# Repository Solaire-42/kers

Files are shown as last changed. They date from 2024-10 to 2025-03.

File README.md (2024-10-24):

# kers
Kinetic Energy Recovery System

⠀⠀⠀⠀⠀⠀⠀⠀⠀⠀⠀⠀⠀⠀⠀⠀⠀⠀⠀⠀⠀⠀⠀⠀⠀⠀⠀⠀⠀⠀⠀⠀⠀⠀⠀⠀⠀⠀⠀⠀⠀⠀⠀⣠⠀⠀⠀⠀⠀⠀⠀⠀⠀⠀⠀⠀⠀
⠀⠀⠀⠀⠀⠀⠀⠀⠀⠀⠀⠀⠀⠀⠀⠀⠀⠀⠀⠀⠀⠀⠀⠀⠀⠀⠀⠀⠀⠀⠀⠀⠀⠀⠀⠀⠀⠀⠀⠸⣿⣿⣿⣿⠀⠀⠀⠀⠀⠀⠀⠀⠀⠀⠀⠀⠀
⠀⠀⠀⠀⠀⠀⠀⠀⠀⠀⠀⠀⠀⠀⠀⠀⠀⠀⠀⠀⠀⠀⠀⠀⠀⠀⠀⠀⠀⠀⠀⠀⠀⠀⠀⠀⠀⠀⢠⣿⣿⣿⠛⠁⠀⠀⠀⠀⠀⠀⠀⠀⠀⠀⠀⠀⠀
⠀⠀⠀⠀⠀⠀⠀⠀⠀⠀⠀⠀⠀⠀⠀⠀⠀⠀⠀⠀⠀⠀⠀⠀⠀⠀⠀⠀⠀⠀⠀⠀⠀⠀⠀⣶⣶⣶⣿⢿⣿⣥⡄⠀⠀⠀⠀⠀⠀⠀⠀⠀⠀⠀⠀⠀⠀
⠀⠀⠀⠀⠀⠀⠀⠀⠀⠀⠀⠀⠀⠀⠀⠀⠀⠀⠀⠀⠀⠀⠀⠀⠀⠀⠀⠀⠀⠀⠀⠀⢀⣤⣾⡿⠟⠉⠀⠸⣿⡄⠀⠀⠀⠀⠀⠀⠀⠀⠀⠀⠀⠀⠀⠀⠀
⠀⠀⠀⠀⠀⠀⠀⠀⠀⠀⠀⠀⠀⠀⠀⠀⠀⠀⠀⠀⠀⠀⠀⠀⠀⠀⠀⠀⠀⢀⣠⣶⠟⠋⠁⠀⠀⠀⠀⠀⣿⣇⠀⠀⠀⠀⠀⠀⠀⠀⠀⠀⠀⠀⠀⠀⠀
⠀⠀⠀⠀⠀⠀⠀⠀⠀⠀⠀⠀⠀⠀⠀⠀⠀⠀⠀⠀⠀⠀⠀⠀⠀⠀⠀⣀⣴⡾⠋⠁⠀⠀⠀⠀⠀⠀⠀⠀⠘⣿⠀⠀⠀⠀⠀⠀⠀⠀⠀⠀⠀⠀⠀⠀⠀
⠀⠀⠀⠀⠀⠀⠀⠀⠀⠀⠀⠀⠀⠀⠀⠀⠀⠀⠀⠀⠀⠀⠀⠀⠀⣠⣾⠟⠁⠀⠀⠀⠀⠀⠀⠀⠀⠀⠀⠀⠀⣿⡇⠀⠀⠀⠀⠀⠀⠀⠀⠀⠀⠀⠀⠀⠀
⠀⠀⠀⠀⠀⠀⠀⠀⠀⠀⠀⠀⠀⠀⠀⠀⠀⠀⠀⠀⠀⠀⠀⢠⣾⠟⠁⠀⠀⠀⠀⠀⠀⠀⠀⠀⠀⠀⠀⠀⠀⠸⣧⠀⠀⠀⠀⠀⠀⠀⠀⠀⠀⠀⠀⠀⠀
⠀⠀⠀⠀⠀⠀⠀⠀⠀⠀⠀⠀⠀⠀⠀⠀⠀⠀⠀⠀⠀⠀⣰⡿⠃⠀⠀⠀⠀⠀⠀⠀⠀⠀⠀⠀⠀⠀⠀⠀⠀⠀⣿⡄⠀⠀⠀⠀⠀⠀⠀⠀⠀⠀⠀⠀⠀
⠀⠀⠀⠀⠀⠀⠀⠀⠀⠀⠀⠀⠀⠀⠀⠀⠀⠀⠀⠀⠀⣼⡟⠀⠀⠀⠀⠀⠀⠀⠀⠀⠀⠀⠀⠀⠀⠀⠀⠀⠀⠀⢸⡇⠀⠀⠀⠀⠀⠀⠀⠀⠀⠀⠀⠀⠀
⠀⠀⠀⠀⠀⠀⠀⠀⠀⠀⠀⠀⠀⠀⠀⠀⠀⠀⠀⠀⣾⡏⠀⠀⠀⠀⠀⠀⠀⠀⠀⠀⠀⠀⠀⠀⠀⠀⠀⠀⠀⠀⢸⣷⠀⠀⠀⠀⠀⠀⠀⠀⠀⠀⠀⠀⠀
⠀⠀⠀⠀⠀⠀⠀⠀⠀⠀⠀⠀⠀⠀⠀⠀⠀⠀⠀⣸⡟⠀⠀⠀⠀⠀⠀⠀⠀⠀⠀⠀⠀⠀⠀⠀⠀⠀⠀⠀⠀⠀⠸⣿⠀⠀⠀⠀⠀⠀⠀⠀⠀⠀⠀⠀⠀
⠀⠀⠀⠀⠀⠀⠀⠀⠀⠀⠀⠀⠀⠀⠀⠀⠀⠀⢰⡿⠁⠀⠀⠀⠀⠀⠀⠀⠀⠀⠀⠀⠀⠀⠀⠀⠀⠀⠀⠀⠀⠀⠀⣿⠀⠀⠀⠀⠀⠀⠀⠀⠀⠀⠀⠀⠀
⠀⠀⠀⠀⠀⠀⠀⠀⠀⠀⠀⠀⠀⠀⠀⠀⠀⠀⣿⡇⠀⠀⠀⠀⠀⠀⠀⠀⠀⠀⠀⠀⠀⠀⠀⠀⠀⠀⠀⠀⠀⠀⠀⣿⠀⠀⠀⠀⠀⠀⠀⠀⠀⠀⠀⠀⠀
⠀⠀⠀⠀⠀⠀⠀⠀⠀⠀⠀⠀⠀⠀⠀⠀⠀⢸⡟⠀⠀⠀⠀⠀⠀⠀⠀⠀⠀⠀⠀⠀⠀⠀⠀⠀⠀⠀⠀⠀⠀⠀⠀⢻⡄⠀⠀⠀⠀⠀⠀⠀⠀⠀⠀⠀⠀
⠀⠀⠀⠀⠀⠀⠀⠀⠀⠀⠀⠀⠀⠀⠀⠀⢠⣿⠁⠀⠀⠀⠀⠀⠀⠀⠀⠀⠀⠀⠀⠀⠀⠀⠀⠀⠀⠀⠀⠀⠀⠀⠀⢸⡇⠀⠀⠀⠀⠀⠀⠀⠀⠀⠀⠀⠀
⠀⠀⠀⠀⠀⠀⠀⠀⣀⣤⣠⣠⣀⣀⣀⣀⣸⣟⡀⠀⠀⠀⠀⠀⠀⠀⠀⠀⠀⠀⠀⠀⠀⠀⠀⠀⠀⠀⠀⠀⠀⠀⠀⢸⡇⠀⠀⠀⠀⠀⠀⠀⠀⠀⠀⠀⠀
⠀⠀⠀⠀⠀⣠⡶⣿⣿⣭⣿⣿⣿⣿⣿⣿⣿⣿⣿⣷⣶⡦⣤⡀⠀⠀⠀⠀⠀⠀⠀⠀⠀⠀⠀⠀⠀⠀⠀⠀⠀⠀⠀⢸⡇⠀⠀⠀⠀⠀⠀⠀⠀⠀⠀⠀⠀
⠀⠀⠀⣠⣾⢿⣿⣿⣿⣿⣿⣿⣿⣿⣿⣿⣿⣿⣿⣿⣿⣿⣮⡙⢷⣄⠀⠀⠀⠀⠀⠀⠀⠀⠀⠀⠀⠀⠀⠀⠀⠀⠀⢸⡇⠀⠀⠀⠀⠀⠀⠀⠀⠀⠀⠀⠀
⠀⢀⣼⢛⣵⣿⣿⣿⣿⣿⣿⣿⣿⣿⣿⣿⣿⣿⣿⣿⣿⣿⣿⣷⡄⠻⣧⡀⠀⠀⠀⠀⠀⠀⠀⠀⠀⠀⠀⠀⠀⠀⠀⢸⡇⠀⠀⠀⠀⠀⠀⠀⠀⠀⠀⠀⠀
⠀⣼⠃⣾⣿⣿⣿⣿⣿⣿⣿⣿⣿⣿⣿⣿⣿⣿⣿⣿⣿⣿⣿⣿⣿⡖⢻⣇⠀⠀⠀⠀⠀⠀⠀⠀⠀⠀⠀⠀⠀⠀⠀⢸⡇⠀⠀⠀⠀⠀⠀⠀⠀⠀⠀⠀⠀
⣸⡿⣴⣿⣿⣿⠟⠛⣿⣿⣿⡿⣿⣿⣿⣿⣿⣿⣿⣿⣿⣿⣿⣿⣿⣿⣾⣿⠀⠀⠀⠀⠀⠀⠀⠀⠀⠀⠀⠀⠀⠀⠀⢸⣧⠀⠀⠀⠀⠀⠀⠀⠀⠀⠀⠀⠀
⣿⡇⣿⣿⣿⡆⠰⠘⠿⠟⠉⠀⠈⢿⣿⣿⣿⣿⣿⣿⣿⣿⣿⣿⣿⣿⣿⣿⠀⠀⠀⠀⠀⠀⠀⢀⣤⣀⣀⠀⠀⠀⠀⢸⣿⠀⠀⠀⠀⠀⠀⠀⠀⠀⠀⠀⠀
⣿⠁⠏⣿⡿⡇⢀⢸⡔⠲⣄⢀⠀⢈⣿⣿⣿⣿⣿⣿⣿⣿⣿⣿⣿⣿⣿⣿⠀⠀⠀⢀⣠⣶⠿⠿⣿⣻⣿⣿⣿⣿⣶⣿⣿⣧⣤⣀⣀⡀⠀⠀⠀⠀⠀⠀⠀
⡟⠀⣄⡟⠇⠁⣼⠈⢻⣦⣙⢳⣆⢈⣿⣿⣿⣿⣿⣿⣿⣿⣿⣿⣿⣿⣿⡟⠀⢠⣴⣿⣿⣷⣾⣿⣿⣿⣿⣿⣿⣿⣿⣿⣿⣿⣿⣿⣿⣿⣷⡶⣤⡀⠀⠀⠀
⣷⡀⣿⣇⠀⠀⠹⣆⠀⠈⠙⢻⠿⣿⣿⣿⣿⣿⣿⣿⣿⣿⣿⣿⣿⣿⡿⠃⣠⣿⣿⣿⣿⣿⣿⣿⣿⣿⣿⣿⣿⣿⣿⣿⣿⣿⣿⣿⣿⣿⣿⣿⣎⠹⣦⠀⠀
⢻⣇⠈⣿⡄⠀⠀⠉⣷⠀⠀⡞⠀⢸⣿⣿⣿⣿⣿⣿⣿⣷⣿⣿⣿⣿⠁⢰⣿⣿⣿⣿⣿⣿⣿⣿⣿⣿⣿⣿⣿⣿⣿⣿⣿⣿⣿⣿⣿⣿⣿⣿⣿⣧⢻⣧⠀
⠘⢿⣆⡘⣿⠷⢤⣤⠼⠿⢴⣯⣠⣾⣿⣿⣿⣿⣿⣿⣿⣿⣿⣿⣿⠇⢠⣿⣿⣿⣿⣿⣿⣿⣿⠟⠿⣿⣿⣿⣿⣿⣿⣿⣿⣿⣿⣿⣿⣿⣿⣿⣿⣿⣿⢿⡇
⠀⠈⣯⣷⡈⣢⣠⣀⣀⡀⣀⣨⣽⣿⣿⣿⣿⣿⣿⣿⣿⣿⣿⣿⠋⠀⢸⣿⣿⢃⣿⣿⣿⣽⣿⣦⣝⠛⠛⡉⠉⢉⣻⣿⣿⣿⣿⣿⣿⣿⣿⣿⣿⣿⣿⣾⣷
⠀⠀⠈⢿⣷⠉⠉⢛⡋⠁⠛⠛⠿⣿⣿⣿⠿⠿⢿⣿⣿⣿⡿⠉⠀⠀⢸⣿⣿⣿⣿⣿⠏⣌⡀⠲⠋⠳⣄⠀⣼⣿⣿⣿⣿⣿⣿⣿⣿⣿⣿⣿⣿⣿⣿⣿⣿
⠀⠀⠀⠀⠙⢷⣄⠈⠙⠠⠄⠱⡘⢛⣶⠾⠿⠿⣿⡿⠟⠋⠀⠀⠀⠀⢸⡿⠛⣿⣿⣿⡘⢿⡃⠈⠻⣇⡀⢦⢀⣿⣿⣿⣿⣿⣿⣿⣿⣿⣿⣿⣿⣿⣿⣿⡿
⠀⠀⠀⠀⠀⠀⠉⠓⠦⠤⣄⣀⣀⣭⡥⠤⠶⠛⠋⠀⠀⠀⠀⠀⠀⠀⠸⣇⠀⠙⠿⣿⣿⣾⣯⣤⣀⣬⣥⣾⡿⠟⣰⣿⣿⣿⣿⣿⣿⣿⣿⣿⣿⣿⣿⣿⠇
⠀⠀⠀⠀⠀⠀⠀⠀⠀⠀⠈⠉⠁⠀⠀⠀⠀⠀⠀⠀⠀⠀⠀⠀⠀⠀⠀⢹⡠⠀⠀⢼⣿⣿⢻⣟⡛⣛⠉⡉⠀⣰⣿⣿⣿⣿⣿⣿⣿⣿⣿⣿⣿⣿⣿⡏⠀
⠀⠀⠀⠀⠀⠀⠀⠀⠀⠀⠀⠀⠀⠀⠀⠀⠀⠀⠀⠀⠀⠀⠀⠀⠀⠀⠀⠈⣷⡆⠀⠀⠿⣿⡇⠉⢻⣿⣿⣥⣴⣿⣿⣿⣿⣿⣿⣿⣿⣿⣿⣿⠿⢿⡟⠀⠀
⠀⠀⠀⠀⠀⠀⠀⠀⠀⠀⠀⠀⠀⠀⠀⠀⠀⠀⠀⠀⠀⠀⠀⠀⠀⠀⠀⠀⠸⣷⠀⠀⠺⣿⡃⣸⣶⣿⣿⣿⣿⣿⣿⣿⣿⣿⣿⣿⣿⣿⣿⡟⢸⠟⠀⠀⠀
⠀⠀⠀⠀⠀⠀⠀⠀⠀⠀⠀⠀⠀⠀⠀⠀⠀⠀⠀⠀⠀⠀⠀⠀⠀⠀⠀⠀⠀⠹⣧⠀⠘⠛⢦⣍⣉⠍⠻⣿⣿⣿⣿⣿⣿⣿⣿⣿⣿⣿⣏⡴⠋⠀⠀⠀⠀
⠀⠀⠀⠀⠀⠀⠀⠀⠀⠀⠀⠀⠀⠀⠀⠀⠀⠀⠀⠀⠀⠀⠀⠀⠀⠀⠀⠀⠀⠀⠘⢧⡀⠀⠀⠈⡉⠙⢣⣽⡿⣽⣿⣿⣿⣿⠿⣻⣯⡶⠛⠀⠀⠀⠀⠀⠀
⠀⠀⠀⠀⠀⠀⠀⠀⠀⠀⠀⠀⠀⠀⠀⠀⠀⠀⠀⠀⠀⠀⠀⠀⠀⠀⠀⠀⠀⠀⠀⠀⠙⢧⣛⠀⠤⠴⢦⣤⣴⠶⠿⣋⣟⣡⡼⠟⠉⠀⠀⠀⠀⠀⠀⠀⠀
⠀⠀⠀⠀⠀⠀⠀⠀⠀⠀⠀⠀⠀⠀⠀⠀⠀⠀⠀⠀⠀⠀⠀⠀⠀⠀⠀⠀⠀⠀⠀⠀⠀⢀⠈⠛⠛⠛⠛⠛⠛⠛⠛⠛⠉⠀⢀⠀⠀⠀⠀⠀⠀⠀⠀⠀⠀

Teams: 

MECHANICS: Stefan & Matthias

ELECTRONICS: Raphael & Peter

SOFTWARE: Lukas & Lukas

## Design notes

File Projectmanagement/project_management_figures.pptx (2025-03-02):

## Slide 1

Sebastian Repetzki & Thomas Gadner
Matthias Posch
Konstrukteur
Stefan Widmann
Konstrukteur
Peter Berer
Elektrotechniker
Raphael Schallhart
Elektrotechniker
Lukas Figl
Softwareentwickler
Lukas Sieß
Softwareentwickler

Projektleitung Mechanik Projektleitung Elektronik

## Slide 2

Konstruktion
Stromlaufplan
Prototyping
Kontrolle
Fertigung
Inbetriebnahme
Software
Feineinstellungen
Funktionstest
Alltagstauglichkeit
Systemgrenzen
Design
Kontroller
Order
Elektrische Komponenten
Mechanische Komponenten
Fahrrad
Tests

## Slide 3

Gehäuse

BLDC-
Radnabenmotor

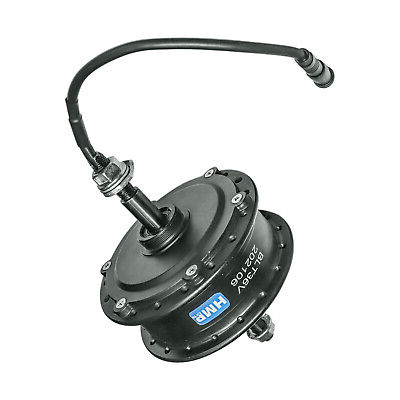
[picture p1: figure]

MCU + Motorkontroller Vorne

MCU + Motorkontroller Hinten

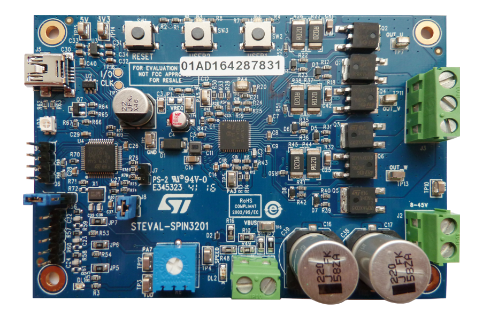
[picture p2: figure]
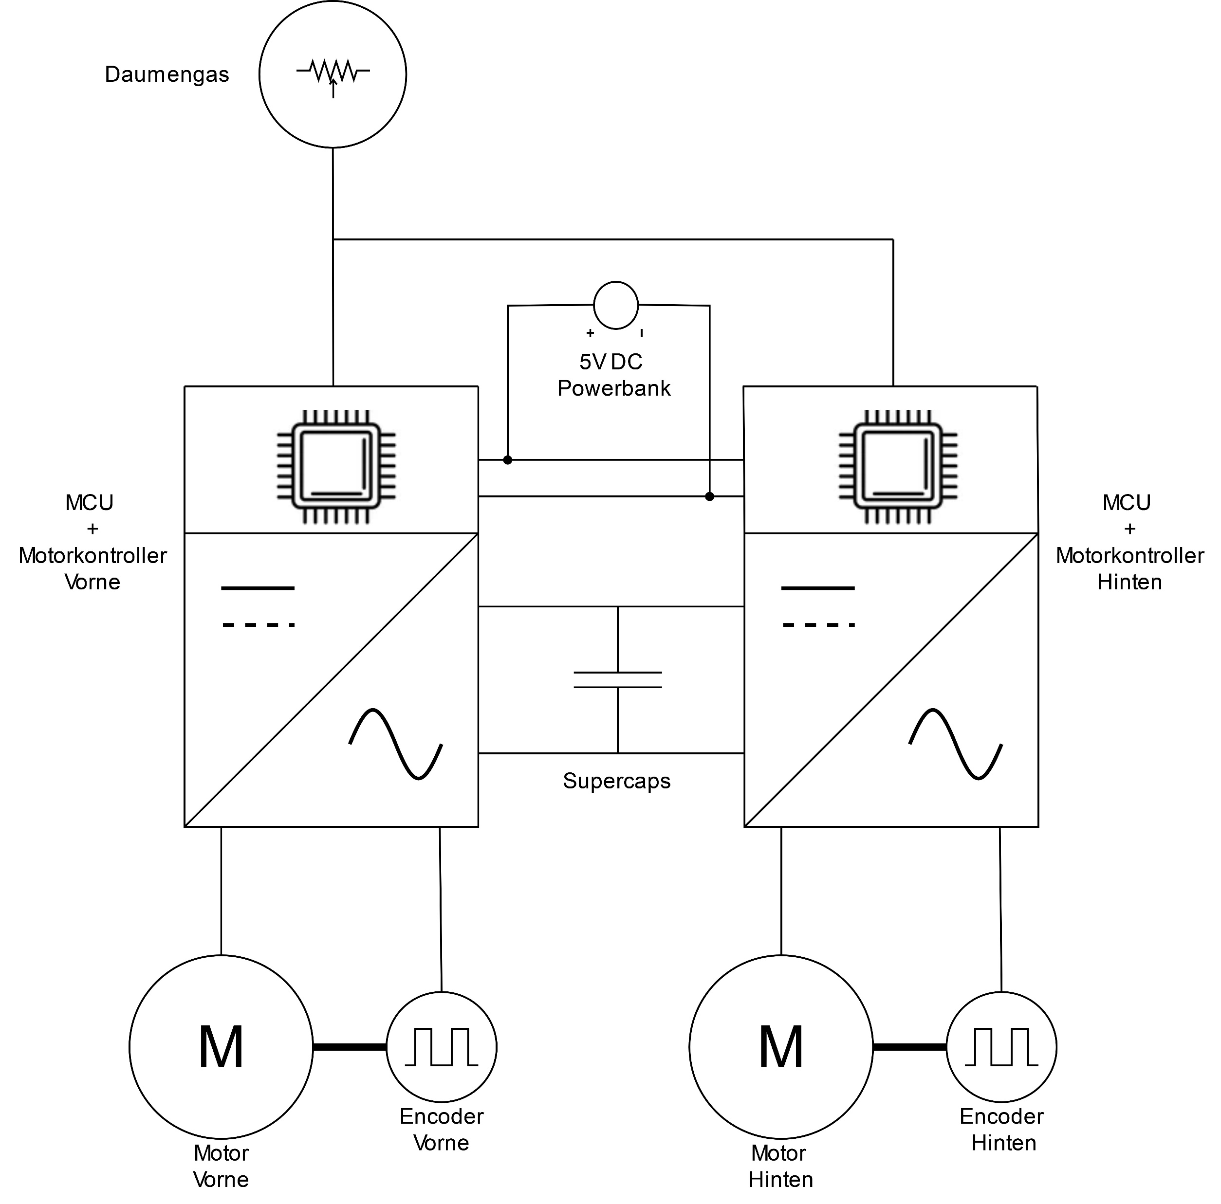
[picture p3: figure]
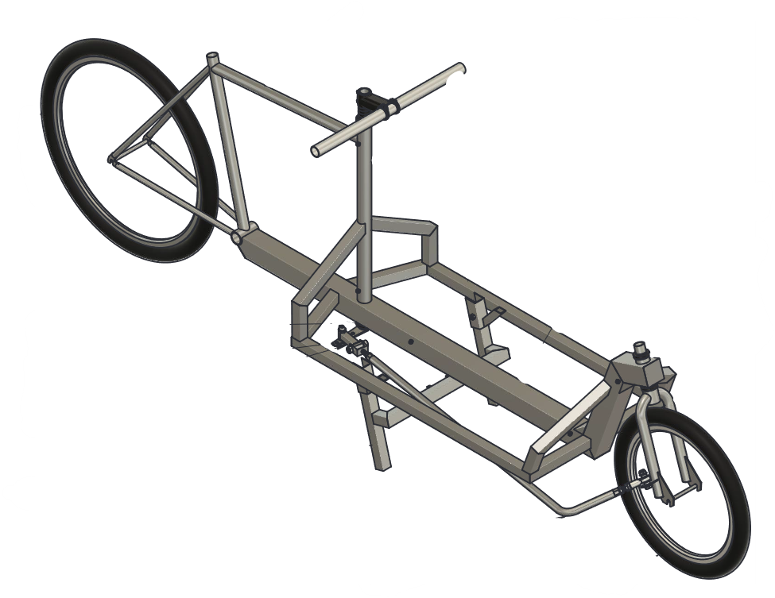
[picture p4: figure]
Ein Bild, das Rad, Reifen, Transport, Bike enthält.

Daumengas

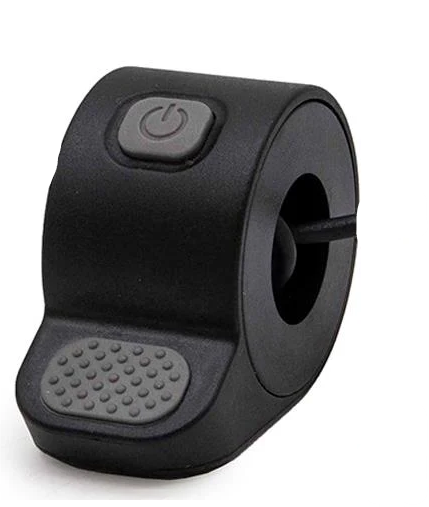
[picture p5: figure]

Powerbank

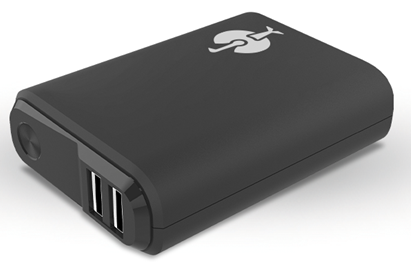
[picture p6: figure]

Batterie

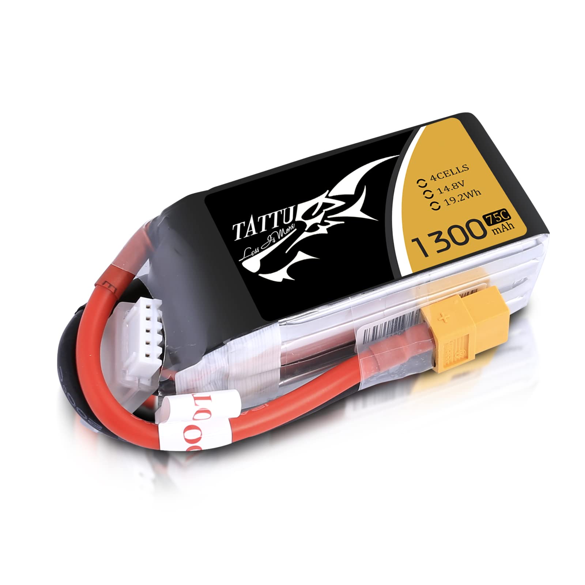
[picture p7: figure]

Supercaps

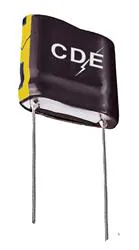
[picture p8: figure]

BLDC-
Radnabenmotor

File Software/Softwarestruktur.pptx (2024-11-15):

## Softwarestruktur

Kers

## Master-Controller - Initialisierung

Initialize_PWM() // PWM für Motorsteuerung
Initialize_ADC() // Sensoren für Strom, Spannung, Temperatur
Initialize_CAN() // CAN-Bus Kommunikation
Initialize_FOC() // FOC-Algorithmus Parameter
Set_CAN_ID(MASTER_ID) // ID für CAN-Nachrichten

## Master-Controller – Main Loop

While True:
Throttle_Input = Read_ADC(THROTTLE_CHANNEL) // Daumengas auslesen
Target_Speed = Map_Throttle_To_Speed(Throttle_Input) // Sollwert berechnen
Send_CAN_Message(SLAVE_ID, Target_Speed) // Sollwert an Slave senden
Motor_Status = Run_FOC(Target_Speed) // FOC-Algorithmus für Beschleunigung
If Motor_Status == ERROR: // Überwachung auf Fehler
Handle_Error(Motor_Status)
CAN_Message = Receive_CAN_Message() // Nachricht von Slave empfangen
If CAN_Message.Type == STATUS_UPDATE:
Update_Display(CAN_Message.Data)

## Slave-Controller - Initialisierung

Initialize_PWM() // PWM für Motorsteuerung
Initialize_ADC() // Sensoren für Strom, Spannung, Temperatur
Initialize_CAN() // CAN-Bus Kommunikation
Initialize_FOC() // FOC-Algorithmus Parameter
Set_CAN_ID(SLAVE_ID) // ID für CAN-Nachrichten

## Slave-Controller – Main Loop

While True:
CAN_Message = Receive_CAN_Message() // Nachricht vom Master empfangen
If CAN_Message.Type == TARGET_SPEED:
Target_Braking = CAN_Message.Data // Zielwert für Bremsen
If Target_Braking > 0:
Energy_Stored = Perform_KERS(Target_Braking) // Energie speichern
Else:
Run_FOC(Target_Braking) // FOC für Bremsen
Motor_Status = Monitor_Motor() // Überwachung des Motors
Send_CAN_Message(MASTER_ID, Motor_Status) // Status an Master zurücksenden

## FOC Algorithmus

Function Run_FOC(Target_Speed):
Phase_Currents = Read_ADC_Phase_Currents() // Strommessung
Rotor_Position = Read_Encoder() // Rotorlage bestimmen
dq_Currents = Clarke_Park_Transform(Phase_Currents, Rotor_Position) // Transformation
dq_Voltages = PI_Controller(dq_Currents, Target_Speed) // Regelung im dq-Raum
PWM_Signals = SVPWM(dq_Voltages) // Raumzeigermodulation
Set_PWM(PWM_Signals) // PWM-Ausgabe an Motor
Return Check_Status() // Motorstatus zurückgeben

## FOC KERS (Rekuperation)

Function Perform_KERS(Target_Braking):
Phase_Currents = Read_ADC_Phase_Currents() // Strommessung
Rotor_Position = Read_Encoder() // Rotorlage bestimmen
dq_Currents = Clarke_Park_Transform(Phase_Currents, Rotor_Position) // Transformation
If dq_Currents > Threshold:
Charge_Capacitor(dq_Currents) // Energie in Speicher leiten
Else:
Discharge_Capacitor() // Speicher entladen, wenn nötig
Return Energy_Stored

## CAN-Bus Kommunikation

Function Send_CAN_Message(Target_ID, Data):
CAN_Frame = Create_CAN_Frame(Target_ID, Data)
Transmit_CAN_Frame(CAN_Frame)
Function Receive_CAN_Message():
If CAN_Frame_Received():
Return Parse_CAN_Frame()
Else:
Return NULL

## Fehlerbehandlung

Function Handle_Error(Error_Code):
If Error_Code == OVERCURRENT:
Disable_PWM()
If Error_Code == OVERHEATING:
Reduce_Power()
Log_Error(Error_Code)

## Softwarestruktur

Kers

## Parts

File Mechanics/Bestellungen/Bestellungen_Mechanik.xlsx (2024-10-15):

Stefan Amazon (selbst bezahlt)
 | Stk | Preis/Stk | Gesamt
Bremsen | 1 | 23.18 € | 23.18 € | Chooee Fahrrad V Bremse,Aluminium V-Brake Bremsen Set Schwarz/Rot (https://www.amazon.de/dp/B083S8XQH6?ref=ppx_yo2ov_dt_b_fed_asin_title&th=1)
Schalthebel+Bremshebel | 1 | 21.17 € | 21.17 € | Schalthebel Fahrrad 3x7 Kombination aus Schalthebel Schalthebel 7 Fach Gangschaltung Fahrrad Schalthebel Bremshebel 3 Gang Schalthebel Schalt Bremshebel für Moutain Bike Rennrad Radfahren 1 Paar (https://www.amazon.de/dp/B0B5L5GMF1?ref=ppx_yo2ov_dt_b_fed_asin_title)
Bremsseil | 2 | 10.07 € | 20.14 € | TAPKUA Fahrrad Bremszughülle, 3M Schlauch mit 2500mm Universal Bremszüge Innenkabel für Fahrrad Mountainbike usw (Neutrals Rot) (https://www.amazon.de/dp/B0D2PDYQWH?ref=ppx_yo2ov_dt_b_fed_asin_title&th=1)
Kette | 1 | 13.46 € | 13.46 € | ZONKIE Fahrrad Kette 6/7/8-fach 1/2 x 3/32 Inch 116 Glieder I Kompatibel mit Shimano, SRAM, KMC, Connex I Inkl. Kettenschloss (https://www.amazon.de/dp/B078HVWW4B?ref=ppx_yo2ov_dt_b_fed_asin_title)
Clips | 1 | 6.14 € | 6.14 € | Fahrrad C-Clip Kabelführung, 10 Stück Aluminium Fahrradrahmen C Schnalle, Fahrradkabelführungsschnalle, Mountainbike Bremskabel Kabelführung, für Fahrradbremskabel Schaltkabel Übertragungskabel (https://www.amazon.de/dp/B0CFL118NG?ref=ppx_yo2ov_dt_b_fed_asin_title&th=1)
Lager Lenkung | 1 | 13.10 € | 13.10 € | XiKe 6804-2RS Kugellager 20x32x7mm Chromstahl｜Vorgeschmiert｜Gummi Doppeldichtung, 6804RS Rillenkugellager mit Abdeckungen, 10er-Packung (https://www.amazon.de/dp/B09SCSHFQZ?ref=ppx_yo2ov_dt_b_fed_asin_title)
Div. Blechschrauben | 1 | 9.67 € | 9.67 € | Annyswit 200 Stück Schwarz Kreuz Blechschrauben Sortiment, M3 M3.5 M4 M5 M6 Kleine Selbstschneidende Schraubenset, Kohlenstoffstahl Screws, Blechschrauben Selbstschneidend für Hausgemachte Reparatur (https://www.amazon.de/dp/B0D53J8LH2?ref=ppx_yo2ov_dt_b_fed_asin_title)
Gelenkkopf | 1 | 17.14 € | 17.14 € | 4 Stück Gelenkkopf Gelenkkopflager Außengewinde Gelenk Gelenkkopf Performance-Gelenkkopf Uniballgelenk Gelenklager (M10) (https://www.amazon.de/dp/B0C944JBXQ?ref=ppx_yo2ov_dt_b_fed_asin_title&th=1)
Verbindungsmutter M10 | 1 | 5.99 € | 5.99 € | 8X M10x50 Verbindungsmuttern Langmuttern Gewindehülsen Distanzmuffen Gewindemuffen Sechskant galv. Verzinkt SW 13 M10 x 50 8 Stück (https://www.amazon.de/dp/B081M21C7T?ref=ppx_yo2ov_dt_b_fed_asin_title)
Verbindungsmutter M6 | 1 | 6.90 € | 6.90 € | 10X M6x50 Verbindungsmuttern Langmuttern Gewindehülsen Distanzmuffen Gewindemuffen Sechskant galv. Verzinkt SW 10 M6 x 50 10 Stück (https://www.amazon.de/dp/B081LWLB5C?ref=ppx_yo2ov_dt_b_fed_asin_title)
Gewindestange | 1 | 7.55 € | 7.55 € | HELPMATE – Gewindestange M10 x 330 mm aus verzinktem Stahl – 2 Stück Gewindestab mit metrischem Vollgewinde – Gewindestift mit Festigkeitsklasse 4.8, DIN 976 (https://www.amazon.de/dp/B0B51H9BXT?ref=ppx_yo2ov_dt_b_fed_asin_title)
Federn
Summe gesamt |  |  | 144.44 €
FixMetall MCI
Stk. | Länge / mm | Material | Dimensionen
2 | 2000 | S235/S235 JR | 60x60x1,5 | 4-kant
3 | 2000 | S235/S235 JR | 30x30x1,5 | 4-kant
1 | 1000 | S235/S235 JR | 35x35x2 | 4-kant
1 | 1000 | S235/S235 JR | 20x20x2 | 4-kant
1 | 2000 | S235/S235 JR | 38x2 | rund
1 | 2000 | S235/S235 JR | 20x1,5 | rund
1 | 1000 | S235/S235 JR | 25x1,5 | rund
Summe gesamt: |  |  | 235.14 €
Fahrräder (selbst bezahlt)
Kleines Fahrrad |  |  | 15.00 €
Großes Fahrrad |  |  | 30.00 €
Summe gesamt: |  |  | 45.00 €

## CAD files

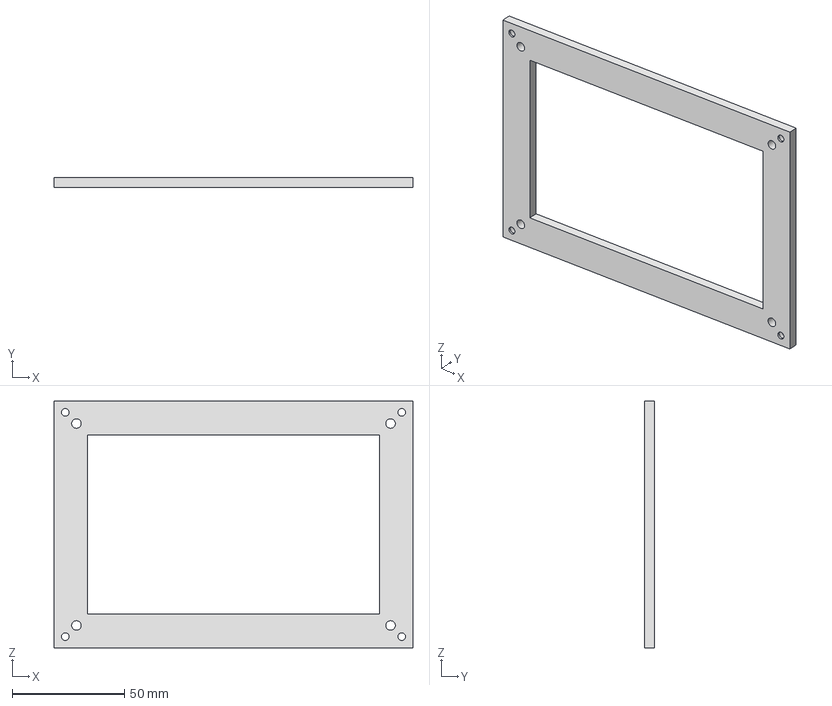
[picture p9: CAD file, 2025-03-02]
Mechanics/Ele-Box/Platinenadapter.stp
160.0 x 4.50 x 110.0 mm

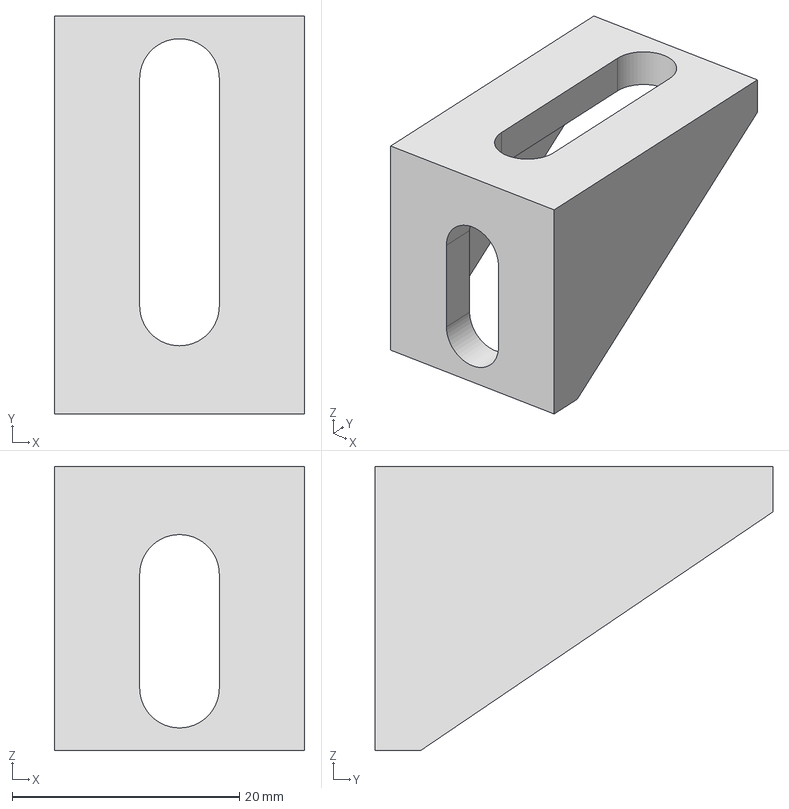
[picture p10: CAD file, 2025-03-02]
Mechanics/Ele-Box/winkel_stark.stp
22.0 x 35.0 x 25.0 mm

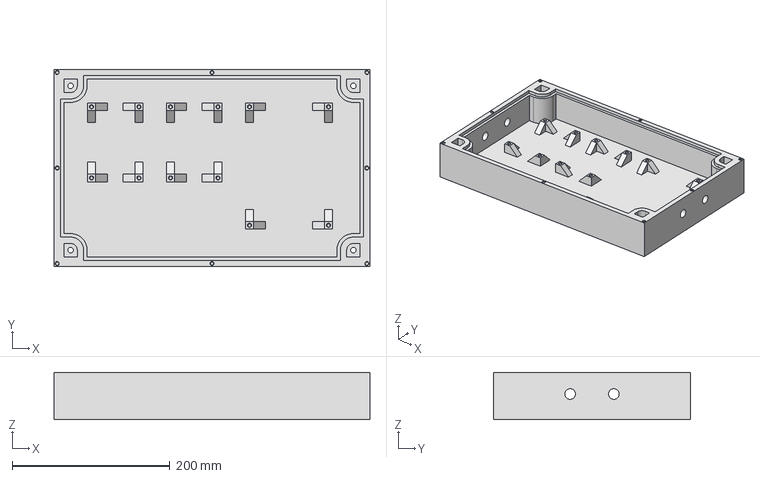
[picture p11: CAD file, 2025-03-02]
Mechanics/Ele-Box/EleBox_unten.stp
400.0 x 250.0 x 60.0 mm

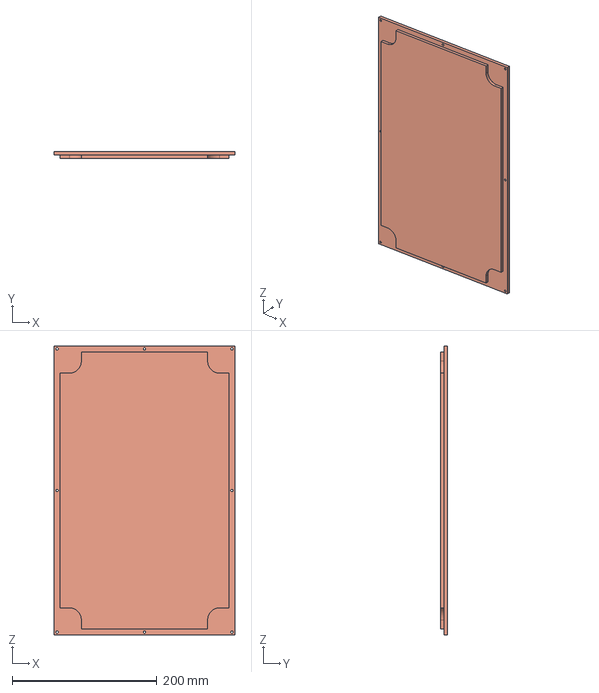
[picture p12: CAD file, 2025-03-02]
Mechanics/Ele-Box/EleBox_oben.stp
250.0 x 10.0 x 400.0 mm

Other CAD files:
Mechanics/cargo_bike/Cargo_Bike_3D_Model.f3d

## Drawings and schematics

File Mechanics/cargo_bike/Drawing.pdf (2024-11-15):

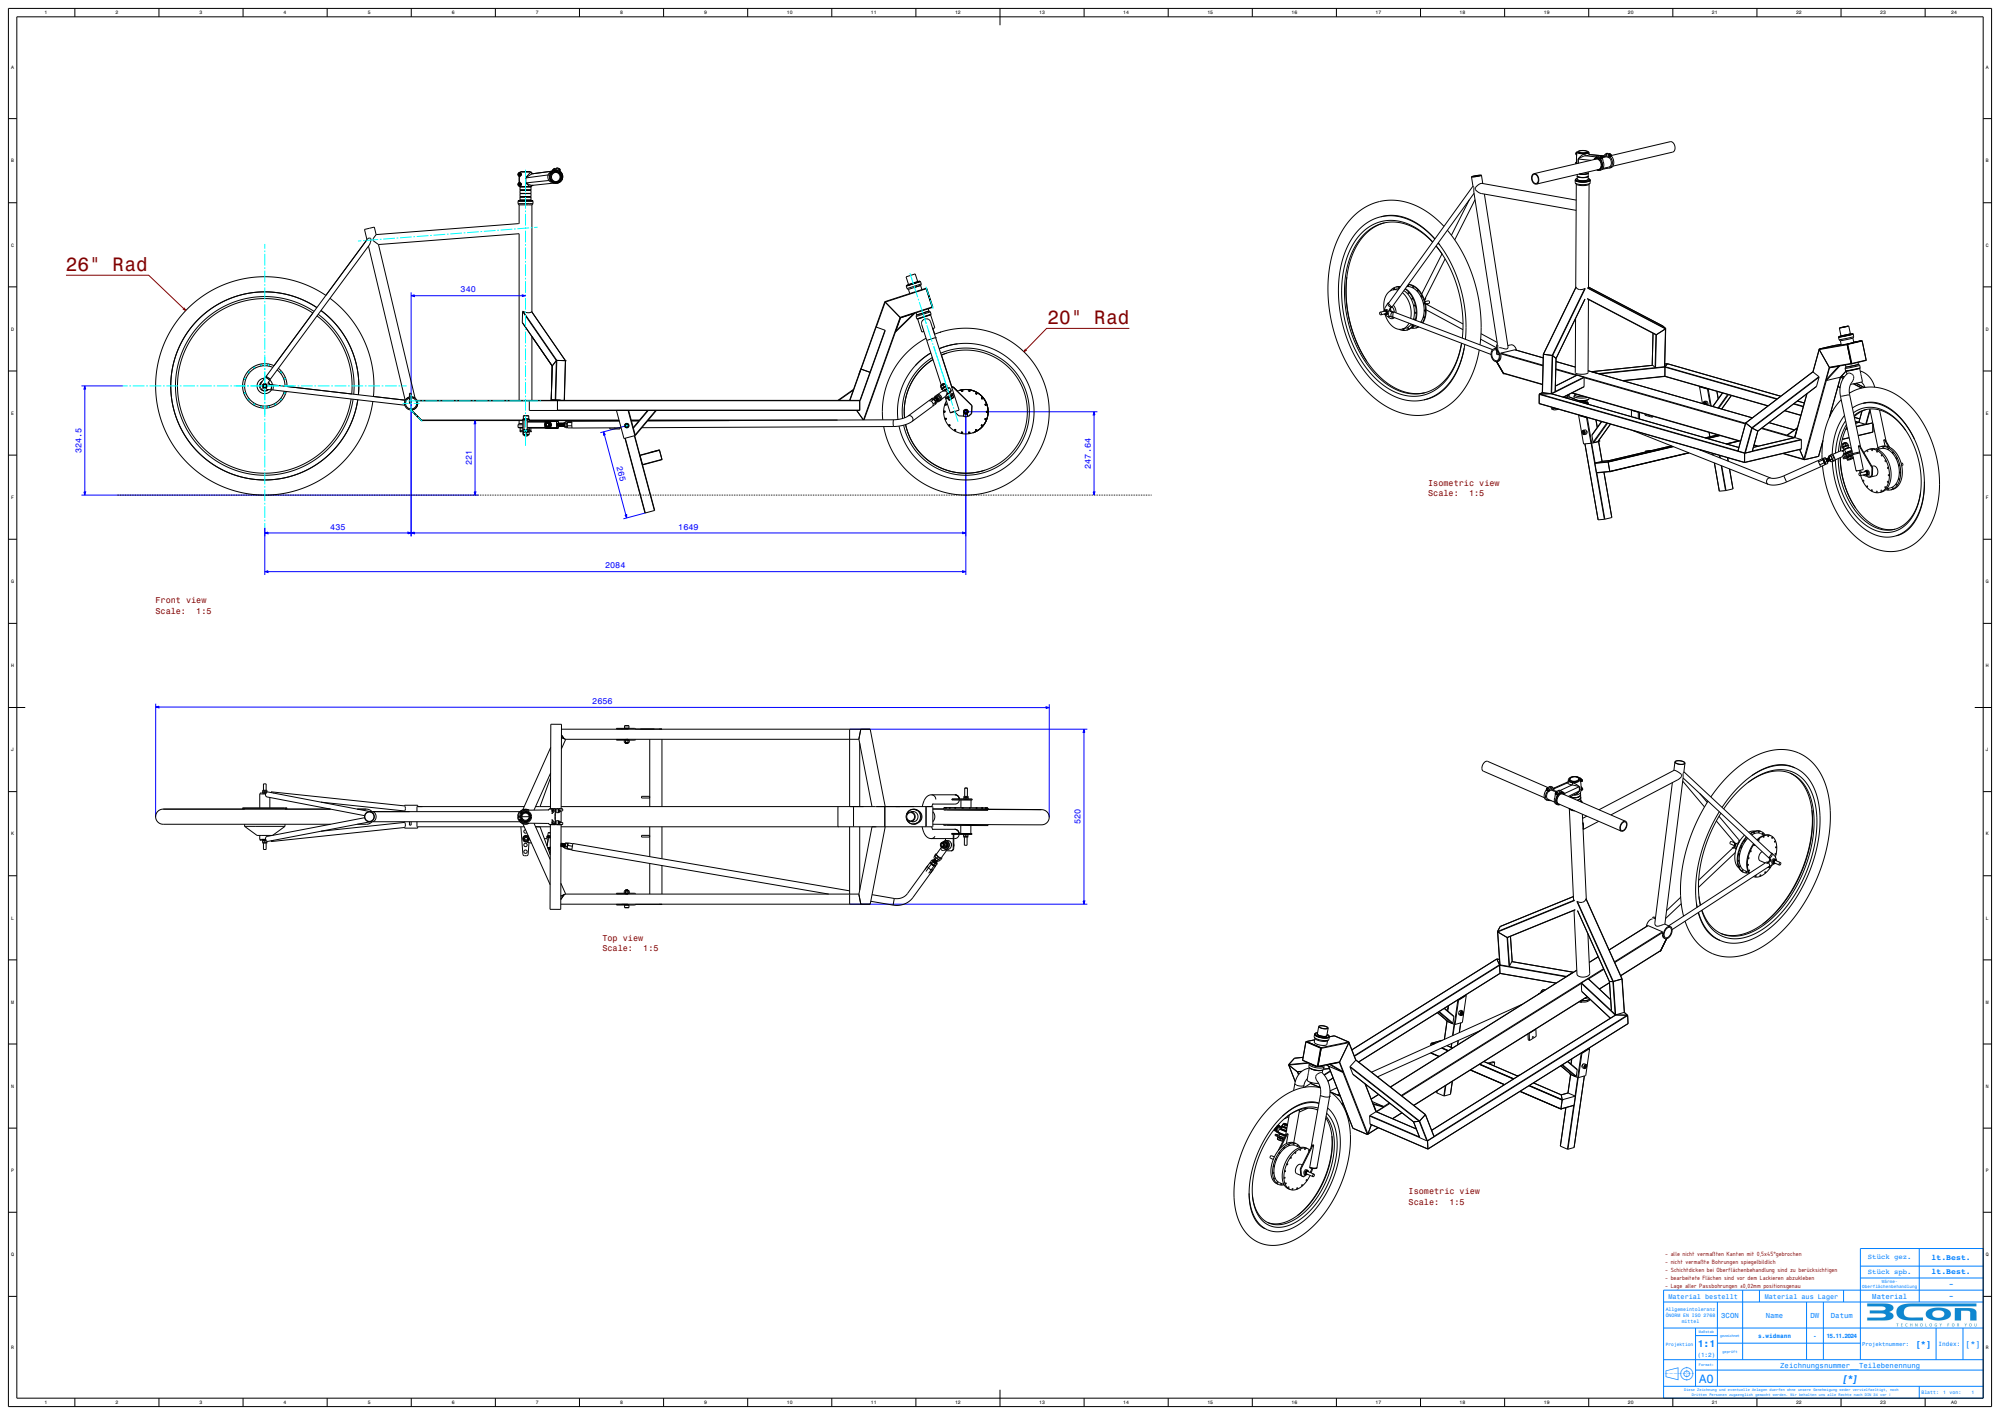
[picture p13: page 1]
Stück gez.; lt.Best.; Stück spb.; Material bestellt; Material aus Lager; Material; Projektnummer: [*] Index: [*]; Format:; Zeichnungsnummer__Teilebenennung; Blatt: 1 von:; 20" Rad; 26" Rad; Front view Scale: 1:5; Isometric view Scale: 1:5; Top view Scale: 1:5

- alle nicht vermaßten Kanten mit 0,5x45°gebrochen
- nicht vermaßte Bohrungen spiegelbildlich
- Schichtdicken bei Oberflächenbehandlung sind zu berücksichtigen
- bearbeitete Flächen sind vor dem Lackieren abzukleben
- Lage aller Passbohrungen ±0,02mm positionsgenau

Allgemeintoleranz
ÖNORM EN ISO 2768
mittel

Diese Zeichnung und eventuelle Anlagen duerfen ohne unsere Genehmigung weder vervielfaeltigt, noch
Dritten Personen zugaenglich gemacht werden. Wir behalten uns alle Rechte nach DIN 34 vor !

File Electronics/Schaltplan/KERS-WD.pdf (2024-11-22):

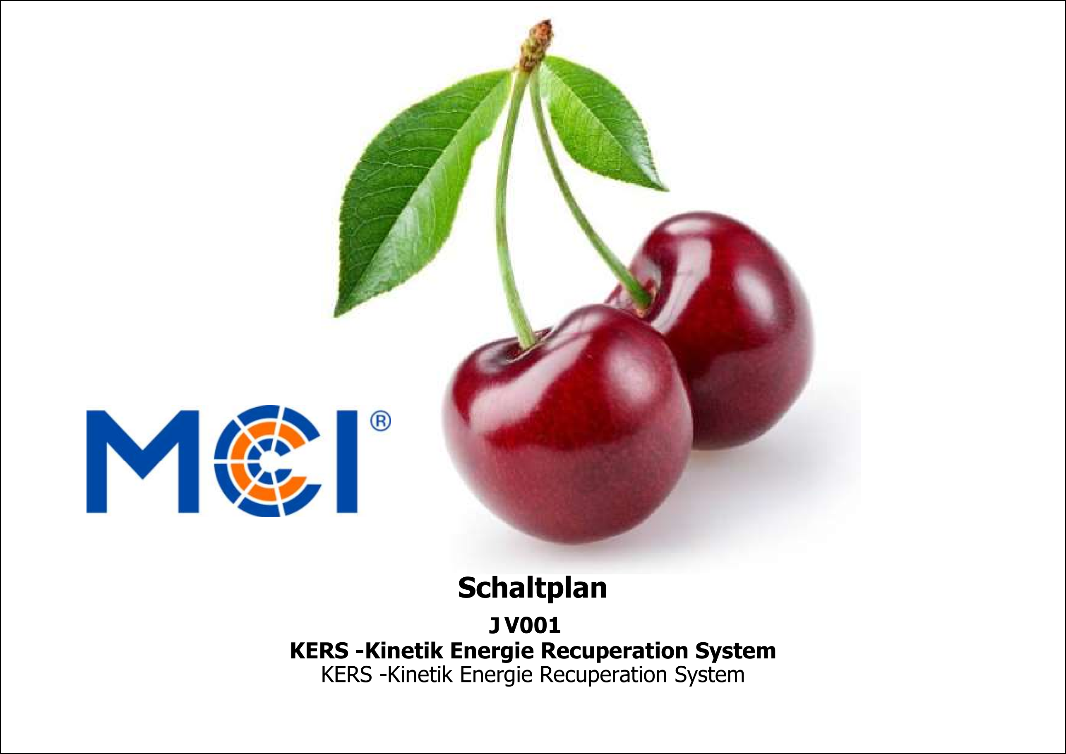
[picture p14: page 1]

# Schaltplan

V001

# KERS -Kinetik Energie Recuperation System KERS -Kinetik Energie Recuperation System

J

1
| | 22.11.2024 | KERS -Kinetik Energie Recuperation System KERS -Kinetik Energie Recuperation System | Titel- / Deckblatt Title page / cover sheet | SO-Nr. Number 00001 Project: | = A1
| Check Date Desig. | Berer Peter
| Print
Revision index | | | C:\Users\bererpe00\OneDrive - INNIO\Desktop\Allgemein\Proje
Drawing | +
V001 Wiring Diagram | Page 2

1

0 7 6

3 | 8 | 9

3

2 4

5

22.11.2024 | J | Die Informationen in diesem Dokument sind geschützte Informationen der INNIO Jenbacher GmbH & Co OG und deren Tochtergesellschaften und vertraulich. Sie sind Eigentum von INNIO und dürfen ohne vorherige schriftliche Genehmigung nicht verwendet, an Dritte weitergeleitet oder vervielfältigt werden. Hierzu zählt auch, aber nicht ausschließlich, die Nutzung der Informationen zur Erstellung, Herstellung, Entwicklung oder Ableitung von Reparaturen, Modifizierungen, Ersatzteilen, Konstruktionen oder Konfigurationsänderungen oder deren Beantragung bei staatlichen Behörden. Wenn die vollständige oder teilweise Vervielfältigung genehmigt wurde, sind dieser Hinweis sowie der weitere Hinweis auf allen Seiten dieses Dokuments ganz oder teilweise zu vermerken. © Copyright GEDRUCKTE ODER ELEKTRONISCH VERMITTELTE VERSIONEN SIND NICHT KONTROLLIERT Eigentumsrechtlicher Hinweis von INNIO: VERTRAULICH ²⁰²⁴
kte\Sonstiges\KERS\KERS.elk | AUTO | INNIO Austria GmbH
AUTO | V001

# KERS -Kinetik Energie Recuperation System

# KERS -Kinetik Energie Recuperation System

# Wiring diagram

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

# Der Schaltplan umfasst Blätter 10

J

# © Copyright 2024

# Eigentumsrechtlicher Hinweis von INNIO: VERTRAULICH

# GEDRUCKTE ODER ELEKTRONISCH VERMITTELTE VERSIONEN SIND NICHT KONTROLLIERT

# INNIO Austria GmbH

2

# Revisionsübersicht Revision summary

4

2024KW21 | SGMACRO\U_20.emp | J | Die Informationen in diesem Dokument sind geschützte Informationen der INNIO Jenbacher GmbH & Co OG und deren Tochtergesellschaften und vertraulich. Sie sind Eigentum von INNIO und dürfen ohne vorherige schriftliche Genehmigung nicht verwendet, an Dritte weitergeleitet oder vervielfältigt werden. Hierzu zählt auch, aber nicht ausschließlich, die Nutzung der Informationen zur Erstellung, Herstellung, Entwicklung oder Ableitung von Reparaturen, Modifizierungen, Ersatzteilen, Konstruktionen oder Konfigurationsänderungen oder deren Beantragung bei staatlichen Behörden. Wenn die vollständige oder teilweise Vervielfältigung genehmigt wurde, sind dieser Hinweis sowie der weitere Hinweis auf allen Seiten dieses Dokuments ganz oder teilweise zu vermerken. © Copyright GEDRUCKTE ODER ELEKTRONISCH VERMITTELTE VERSIONEN SIND NICHT KONTROLLIERT Eigentumsrechtlicher Hinweis von INNIO: VERTRAULICH ²⁰²⁴

# Page 3

kte\Sonstiges\KERS\KERS.elk | AUTO | INNIO Austria GmbH

# Informationen (allgemein) information (general)

# Revisionsübersicht Revision summary

Version Version | Datum Date | Freigabe: Name Release: Name | Änderungen: Gruppen Modifications: Groups | Status: Änderung Status: Revision | Bemerkung Comment
- | 11.11.2024 | Berer P.; Schallhart R. | AllGroups | Vor Fertigung - Before manufacturing | Schaltplan kreiert - Wiring diagram created

# +BAT1
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

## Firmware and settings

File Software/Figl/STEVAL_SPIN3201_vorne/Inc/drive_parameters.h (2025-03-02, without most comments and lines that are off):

#define DRIVE_PARAMETERS_H
#define MAX_APPLICATION_SPEED_RPM           972
#define MIN_APPLICATION_SPEED_RPM           0
#define M1_SS_MEAS_ERRORS_BEFORE_FAULTS     3
#define VARIANCE_THRESHOLD                  0.25
#define F1                                  16384
#define F2                                  16384
#define F1_LOG                              LOG2((16384))
#define F2_LOG                              LOG2((16384))
#define GAIN1                               -23698
#define GAIN2                               14160
#define PLL_KP_GAIN                         517
#define PLL_KI_GAIN                         37
#define PLL_KPDIV                           16384
#define PLL_KPDIV_LOG                       LOG2((PLL_KPDIV))
#define PLL_KIDIV                           65535
#define PLL_KIDIV_LOG                       LOG2((PLL_KIDIV))
#define STO_FIFO_DEPTH_DPP                  64
#define STO_FIFO_DEPTH_DPP_LOG              LOG2((64))
#define STO_FIFO_DEPTH_UNIT                 64
#define M1_BEMF_CONSISTENCY_TOL             64
#define M1_BEMF_CONSISTENCY_GAIN            64
#define PARK_ANGLE_COMPENSATION_FACTOR      0
#define REV_PARK_ANGLE_COMPENSATION_FACTOR  0
#define PWM_FREQUENCY                       30000
#define PWM_FREQ_SCALING                    1
#define LOW_SIDE_SIGNALS_ENABLING           LS_PWM_TIMER
#define SW_DEADTIME_NS                      700
#define REGULATION_EXECUTION_RATE           3
#define ISR_FREQUENCY_HZ                    (PWM_FREQUENCY/REGULATION_EXECUTION_RATE)
#define PID_TORQUE_KP_DEFAULT               2036
#define PID_TORQUE_KI_DEFAULT               1164
#define PID_TORQUE_KD_DEFAULT               100
#define PID_FLUX_KP_DEFAULT                 2036
#define PID_FLUX_KI_DEFAULT                 1164
#define PID_FLUX_KD_DEFAULT                 100
#define TF_KPDIV                            2048
#define TF_KIDIV                            16384
#define TF_KDDIV                            8192
#define TF_KPDIV_LOG                        LOG2((2048))
#define TF_KIDIV_LOG                        LOG2((16384))
#define TF_KDDIV_LOG                        LOG2((8192))
#define TFDIFFERENTIAL_TERM_ENABLING        DISABLE
#define PID_SPEED_KP_DEFAULT                3389/(SPEED_UNIT/10)
#define PID_SPEED_KI_DEFAULT                3735/(SPEED_UNIT/10)
#define PID_SPEED_KD_DEFAULT                0/(SPEED_UNIT/10)
#define SPEED_LOOP_FREQUENCY_HZ             (uint16_t)10
#define SP_KPDIV                            64
#define SP_KIDIV                            1024
#define SP_KDDIV                            16
#define SP_KPDIV_LOG                        LOG2((64))
#define SP_KIDIV_LOG                        LOG2((1024))
#define SP_KDDIV_LOG                        LOG2((16))
#define PID_SPEED_INTEGRAL_INIT_DIV         1
#define SPD_DIFFERENTIAL_TERM_ENABLING      DISABLE
#define IQMAX_A                             14
#define DEFAULT_CONTROL_MODE                MCM_SPEED_MODE
#define DEFAULT_TARGET_SPEED_RPM            500
#define DEFAULT_TARGET_SPEED_UNIT           (DEFAULT_TARGET_SPEED_RPM*SPEED_UNIT/U_RPM)
#define DEFAULT_TORQUE_COMPONENT_A          0
#define DEFAULT_FLUX_COMPONENT_A            0
#define OV_VOLTAGE_THRESHOLD_V              45
#define UD_VOLTAGE_THRESHOLD_V              8
#ifdef NOT_IMPLEMENTED
#define ON_OVER_VOLTAGE                     TURN_OFF_PWM
#endif
#define OV_TEMPERATURE_THRESHOLD_C          70
#define OV_TEMPERATURE_HYSTERESIS_C         10
#define HW_OV_CURRENT_PROT_BYPASS           DISABLE
#define OVP_INVERTINGINPUT_MODE             INT_MODE
#define OVP_INVERTINGINPUT_MODE2            INT_MODE
#define OVP_SELECTION                       COMP_Selection_COMP1
#define OVP_SELECTION2                      COMP_Selection_COMP1
#define PHASE1_DURATION                     1000
#define PHASE1_FINAL_SPEED_UNIT             (0*SPEED_UNIT/U_RPM)
#define PHASE1_FINAL_CURRENT_A              0
#define PHASE2_DURATION                     1000
#define PHASE2_FINAL_SPEED_UNIT             (0*SPEED_UNIT/U_RPM)
#define PHASE2_FINAL_CURRENT_A              0
#define PHASE3_DURATION                     3000
#define PHASE3_FINAL_SPEED_UNIT             (100*SPEED_UNIT/U_RPM)
#define PHASE3_FINAL_CURRENT_A              10
#define PHASE4_DURATION                     3000
#define PHASE4_FINAL_SPEED_UNIT             (500*SPEED_UNIT/U_RPM)
#define PHASE4_FINAL_CURRENT_A              10
#define PHASE5_DURATION                     4000
#define PHASE5_FINAL_SPEED_UNIT             (955*SPEED_UNIT/U_RPM)
#define PHASE5_FINAL_CURRENT_A              10
#define ENABLE_SL_ALGO_FROM_PHASE           1
#define STARTING_ANGLE_DEG                  0
#define OBS_MINIMUM_SPEED_RPM               350
#define NB_CONSECUTIVE_TESTS                2
#define SPEED_BAND_UPPER_LIMIT              17
#define SPEED_BAND_LOWER_LIMIT              15
#define TRANSITION_DURATION                 0
#define  M1_VBUS_SAMPLING_TIME              LL_ADC_SAMPLING_CYCLE(28)
#define ADC_SAMPLING_CYCLES                 (7 + SAMPLING_CYCLE_CORRECTION)

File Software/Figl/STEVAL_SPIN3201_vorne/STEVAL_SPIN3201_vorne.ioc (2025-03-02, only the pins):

Mcu.UserName=STM32F031C6Tx
PA10.GPIO_Label=M1_PWM_WH
PA10.Signal=S_TIM1_CH3
PA11.GPIO_Label=OC_SEL
PA11.Signal=GPIO_Output
PA12.GPIO_Label=_3FG_HIZ
PA12.Signal=GPIO_Output
PA13.GPIO_Label=TMS
PA13.Signal=SYS_SWDIO
PA14.GPIO_Label=TCK
PA14.Signal=SYS_SWCLK
PA3.GPIO_Label=M1_CURR_AMPL_W
PA3.Signal=ADC_IN3
PA4.GPIO_Label=M1_CURR_AMPL_V
PA4.Signal=ADC_IN4
PA5.GPIO_Label=M1_CURR_AMPL_U
PA5.Signal=ADC_IN5
PA8.GPIO_Label=M1_PWM_UH
PA8.Signal=S_TIM1_CH1
PA9.GPIO_Label=M1_PWM_VH
PA9.Signal=S_TIM1_CH2
PB1.GPIO_Label=M1_BUS_VOLTAGE
PB1.Signal=ADC_IN9
PB12.GPIO_Label=M1_OCP
PB12.Signal=TIM1_BKIN
PB13.GPIO_Label=M1_PWM_UL
PB13.Signal=TIM1_CH1N
PB14.GPIO_Label=M1_PWM_VL
PB14.Signal=TIM1_CH2N
PB15.GPIO_Label=M1_PWM_WL
PB15.Signal=TIM1_CH3N
PB6.GPIO_Label=UART_TX
PB6.Signal=USART1_TX
PB7.GPIO_Label=UART_RX
PB7.Signal=USART1_RX
PF0-OSC_IN.GPIO_Label=Start/Stop [PushButton]
PF0-OSC_IN.Signal=GPXTI0
PF6.GPIO_Label=OCTH_STBY2
PF6.Signal=GPIO_Output
PF7.GPIO_Label=OCTH_STBY1
PF7.Signal=GPIO_Output

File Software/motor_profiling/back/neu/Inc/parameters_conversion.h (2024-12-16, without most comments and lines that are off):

#define PARAMETERS_CONVERSION_H
#include "mc_math.h"
#include "parameters_conversion_g4xx.h"
#include "pmsm_motor_parameters.h"
#include "drive_parameters.h"
#include "power_stage_parameters.h"
#define CURRENT_CONV_FACTOR                 (uint16_t)((65536.0 * RSHUNT * AMPLIFICATION_GAIN)/ADC_REFERENCE_VOLTAGE)
#define CURRENT_CONV_FACTOR_INV             (1.0 / ((65536.0 * RSHUNT * AMPLIFICATION_GAIN) / ADC_REFERENCE_VOLTAGE))
#define NOMINAL_CURRENT                     (NOMINAL_CURRENT_A * CURRENT_CONV_FACTOR)
#define ADC_REFERENCE_VOLTAGE               3.3
#define M1_MAX_READABLE_CURRENT  (ADC_REFERENCE_VOLTAGE / (2 * RSHUNT * AMPLIFICATION_GAIN))
#define TF_REGULATION_RATE                  (uint32_t)((uint32_t)(PWM_FREQUENCY) / (REGULATION_EXECUTION_RATE))
#define TF_REGULATION_RATE_SCALED           (uint16_t)((uint32_t)(PWM_FREQUENCY) / (REGULATION_EXECUTION_RATE\
                                            * PWM_FREQ_SCALING))
#define DPP_CONV_FACTOR                     (65536 / PWM_FREQ_SCALING)
#define ID_DEMAG                            (ID_DEMAG_A * CURRENT_CONV_FACTOR)
#define IQMAX                               (IQMAX_A * CURRENT_CONV_FACTOR)
#define DEFAULT_TORQUE_COMPONENT            (DEFAULT_TORQUE_COMPONENT_A * CURRENT_CONV_FACTOR)
#define DEFAULT_FLUX_COMPONENT              (DEFAULT_FLUX_COMPONENT_A * CURRENT_CONV_FACTOR)
#define REP_COUNTER                         (uint16_t)((REGULATION_EXECUTION_RATE * 2u) - 1u)
#define SYS_TICK_FREQUENCY                  (uint16_t)2000
#define UI_TASK_FREQUENCY_HZ                10U
#define PHASE1_FINAL_CURRENT                (PHASE1_FINAL_CURRENT_A * CURRENT_CONV_FACTOR)
#define PHASE2_FINAL_CURRENT                (PHASE2_FINAL_CURRENT_A * CURRENT_CONV_FACTOR)
#define PHASE3_FINAL_CURRENT                (PHASE3_FINAL_CURRENT_A * CURRENT_CONV_FACTOR)
#define PHASE4_FINAL_CURRENT                (PHASE4_FINAL_CURRENT_A * CURRENT_CONV_FACTOR)
#define PHASE5_FINAL_CURRENT                (PHASE5_FINAL_CURRENT_A * CURRENT_CONV_FACTOR)
#define MEDIUM_FREQUENCY_TASK_RATE          (uint16_t)SPEED_LOOP_FREQUENCY_HZ
#define MF_TASK_OCCURENCE_TICKS             (SYS_TICK_FREQUENCY / SPEED_LOOP_FREQUENCY_HZ) - 1u
#define UI_TASK_OCCURENCE_TICKS             (SYS_TICK_FREQUENCY / UI_TASK_FREQUENCY_HZ) - 1u
#define SERIALCOM_TIMEOUT_OCCURENCE_TICKS   (SYS_TICK_FREQUENCY / SERIAL_COM_TIMEOUT_INVERSE) - 1u
#define SERIALCOM_ATR_TIME_TICKS            (uint16_t)(((SYS_TICK_FREQUENCY * SERIAL_COM_ATR_TIME_MS) / 1000u) - 1u)
#define MAX_BEMF_VOLTAGE                    (uint16_t)((MAX_APPLICATION_SPEED_RPM * 1.2 *\
                                            MOTOR_VOLTAGE_CONSTANT * SQRT_2) / (1000u * SQRT_3))
#define MAX_VOLTAGE                         (int16_t)((ADC_REFERENCE_VOLTAGE / SQRT_3) / VBUS_PARTITIONING_FACTOR)
#define MAX_CURRENT                         (ADC_REFERENCE_VOLTAGE / (2 * RSHUNT * AMPLIFICATION_GAIN))
#define OBS_MINIMUM_SPEED_UNIT              (uint16_t)((OBS_MINIMUM_SPEED_RPM * SPEED_UNIT) / U_RPM)
#define MAX_APPLICATION_SPEED_UNIT          ((MAX_APPLICATION_SPEED_RPM * SPEED_UNIT) / U_RPM)
#define MIN_APPLICATION_SPEED_UNIT          ((MIN_APPLICATION_SPEED_RPM * SPEED_UNIT) / U_RPM)
#define C1                                  (int32_t)((((int16_t)F1) * RS) / (LS * TF_REGULATION_RATE))
#define C2                                  (int32_t)GAIN1
#define C3                                  (int32_t)((((int16_t)F1) * MAX_BEMF_VOLTAGE)\
                                            / (LS * MAX_CURRENT * TF_REGULATION_RATE))
#define C4                                  (int32_t)GAIN2
#define C5                                  (int32_t)((((int16_t)F1) * MAX_VOLTAGE)\
                                            / (LS * MAX_CURRENT * TF_REGULATION_RATE))
#define PERCENTAGE_FACTOR                   (uint16_t)(VARIANCE_THRESHOLD*128u)
#define HFI_MINIMUM_SPEED                   (uint16_t) (HFI_MINIMUM_SPEED_RPM/6u)
#define MAX_APPLICATION_SPEED_UNIT2         ((MAX_APPLICATION_SPEED_RPM2 * SPEED_UNIT) / U_RPM)
#define MIN_APPLICATION_SPEED_UNIT2         ((MIN_APPLICATION_SPEED_RPM2 * SPEED_UNIT) / U_RPM)
#define OVERVOLTAGE_THRESHOLD_d             (uint16_t)(OV_VOLTAGE_THRESHOLD_V * 65535 /\
                                            (ADC_REFERENCE_VOLTAGE / VBUS_PARTITIONING_FACTOR))
#define OVERVOLTAGE_THRESHOLD_LOW_d         (uint16_t)(OV_VOLTAGE_THRESHOLD_V * 65535 /\
                                            (ADC_REFERENCE_VOLTAGE / VBUS_PARTITIONING_FACTOR))
#define UNDERVOLTAGE_THRESHOLD_d            (uint16_t)((UD_VOLTAGE_THRESHOLD_V * 65535) /\
                                            ((uint16_t)(ADC_REFERENCE_VOLTAGE / VBUS_PARTITIONING_FACTOR)))
#define INT_SUPPLY_VOLTAGE                  (uint16_t)(65536 / ADC_REFERENCE_VOLTAGE)
#define DELTA_TEMP_THRESHOLD                (OV_TEMPERATURE_THRESHOLD_C - T0_C)
#define DELTA_V_THRESHOLD                   (dV_dT * DELTA_TEMP_THRESHOLD)
#define OV_TEMPERATURE_THRESHOLD_d          ((V0_V + DELTA_V_THRESHOLD) * INT_SUPPLY_VOLTAGE)
#define DELTA_TEMP_HYSTERESIS               (OV_TEMPERATURE_HYSTERESIS_C)
#define DELTA_V_HYSTERESIS                  (dV_dT * DELTA_TEMP_HYSTERESIS)
#define OV_TEMPERATURE_HYSTERESIS_d         (DELTA_V_HYSTERESIS * INT_SUPPLY_VOLTAGE)
#undef MAX_APPLICATION_SPEED_RPM
#define MAX_APPLICATION_SPEED_RPM           50000
#undef F1
#define F1                                  0
#undef CORD_F1
#define CORD_F1                             0
#define SPEED_REGULATOR_BANDWIDTH           0
#define LDLQ_RATIO                          1.000
#define RESISTOR_OFFSET                     0.02
#define BUS_VOLTAGE_CONVERSION_FACTOR       63.2
#define CURRENT_REGULATOR_BANDWIDTH         6000
#define MP_KP                               1.00f
#define MP_KI                               0.1f
#define DC_CURRENT_RS_MEAS                  ((14) * 80) / 100
#define I_THRESHOLD                         0.05
#define PWM_PERIOD_CYCLES                   (uint16_t)(((uint32_t)ADV_TIM_CLK_MHz * (uint32_t)1000000u\
                                            / ((uint32_t)(PWM_FREQUENCY))) & (uint16_t)0xFFFE)
#define DEADTIME_NS                         SW_DEADTIME_NS
#define DEAD_TIME_ADV_TIM_CLK_MHz           (ADV_TIM_CLK_MHz * TIM_CLOCK_DIVIDER)
#define DEAD_TIME_COUNTS_1                  (DEAD_TIME_ADV_TIM_CLK_MHz * DEADTIME_NS / 1000uL)
#if (DEAD_TIME_COUNTS_1 <= 255)
#define DEAD_TIME_COUNTS                    (uint16_t)DEAD_TIME_COUNTS_1
#elif (DEAD_TIME_COUNTS_1 <= 508)
#define DEAD_TIME_COUNTS                    (uint16_t)(((DEAD_TIME_ADV_TIM_CLK_MHz * DEADTIME_NS/2) /1000uL) + 128)
#elif (DEAD_TIME_COUNTS_1 <= 1008)
#define DEAD_TIME_COUNTS                    (uint16_t)(((DEAD_TIME_ADV_TIM_CLK_MHz * DEADTIME_NS/8) /1000uL) + 320)
#elif (DEAD_TIME_COUNTS_1 <= 2015)
#define DEAD_TIME_COUNTS                    (uint16_t)(((DEAD_TIME_ADV_TIM_CLK_MHz * DEADTIME_NS/16) /1000uL) + 384)
#else
#define DEAD_TIME_COUNTS 510
#endif
#define DTCOMPCNT                           (uint16_t)((DEADTIME_NS * ADV_TIM_CLK_MHz) / 2000)
#define TON_NS                              500
#define TOFF_NS                             500
#define TON                                 (uint16_t)((TON_NS * ADV_TIM_CLK_MHz)  / 2000)
#define TOFF                                (uint16_t)((TOFF_NS * ADV_TIM_CLK_MHz) / 2000)
#define SAMPLING_TIME                       ((ADC_SAMPLING_CYCLES * ADV_TIM_CLK_MHz) / ADC_CLK_MHz)
#define TRISE                               ((TRISE_NS * ADV_TIM_CLK_MHz)/1000uL)
#define TDEAD                               ((uint16_t)((DEADTIME_NS * ADV_TIM_CLK_MHz)/1000))
#define TNOISE                              ((uint16_t)((TNOISE_NS*ADV_TIM_CLK_MHz)/1000))
#define HTMIN 1
#define TW_AFTER                            ((uint16_t)(((DEADTIME_NS+MAX_TNTR_NS)*ADV_TIM_CLK_MHz)/1000UL))
#define MAX_TWAIT                           ((uint16_t)((TW_AFTER - SAMPLING_TIME)/2))
#define TW_BEFORE                           ((uint16_t)((ADC_TRIG_CONV_LATENCY_CYCLES + ADC_SAMPLING_CYCLES)\
                                            * ADV_TIM_CLK_MHz) / ADC_CLK_MHz  + 1u)
#define TW_BEFORE_R3_1                      ((uint16_t)((ADC_TRIG_CONV_LATENCY_CYCLES + (ADC_SAMPLING_CYCLES * 2)\
                                            + ADC_SAR_CYCLES) * ADV_TIM_CLK_MHz) / ADC_CLK_MHz  + 1u)
#define M1_VIRTUAL_HEAT_SINK_TEMPERATURE_VALUE 25u
#define M1_TEMP_SW_FILTER_BW_FACTOR         250u
#define PQD_CONVERSION_FACTOR               (float_t)(((1.732 * ADC_REFERENCE_VOLTAGE) /\
                                            (RSHUNT * AMPLIFICATION_GAIN)) / 65536.0f)
#define DAC_ENABLE
#define DAC_OP_ENABLE
#define FW_ENABLE
#define DIFFTERM_ENABLE
#define MAIN_SCFG                           UI_SCODE_STO_PLL
#define AUX_SCFG                               0x0
#define PLLTUNING_ENABLE
#define UI_CFGOPT_PFC_ENABLE
#define UI_CONFIG_M1                        (UI_CFGOPT_NONE DAC_OP_ENABLE FW_ENABLE DIFFTERM_ENABLE\
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

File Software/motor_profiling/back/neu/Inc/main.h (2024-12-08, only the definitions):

#define Start_Stop_Pin GPIO_PIN_13
#define Start_Stop_GPIO_Port GPIOC
#define Start_Stop_EXTI_IRQn EXTI15_10_IRQn
#define M1_CURR_AMPL_W_Pin GPIO_PIN_0
#define M1_CURR_AMPL_W_GPIO_Port GPIOC
#define M1_CURR_AMPL_V_Pin GPIO_PIN_1
#define M1_CURR_AMPL_V_GPIO_Port GPIOC
#define M1_TEMPERATURE_Pin GPIO_PIN_2
#define M1_TEMPERATURE_GPIO_Port GPIOC
#define M1_CURR_AMPL_U_Pin GPIO_PIN_0
#define M1_CURR_AMPL_U_GPIO_Port GPIOA
#define M1_BUS_VOLTAGE_Pin GPIO_PIN_1
#define M1_BUS_VOLTAGE_GPIO_Port GPIOA
#define UART_TX_Pin GPIO_PIN_2
#define UART_TX_GPIO_Port GPIOA
#define UART_RX_Pin GPIO_PIN_3
#define UART_RX_GPIO_Port GPIOA
#define M1_OCP_Pin GPIO_PIN_6
#define M1_OCP_GPIO_Port GPIOA
#define M1_PWM_UL_Pin GPIO_PIN_7
#define M1_PWM_UL_GPIO_Port GPIOA
#define M1_PWM_VL_Pin GPIO_PIN_0
#define M1_PWM_VL_GPIO_Port GPIOB
#define M1_PWM_WL_Pin GPIO_PIN_1
#define M1_PWM_WL_GPIO_Port GPIOB
#define M1_PWM_UH_Pin GPIO_PIN_8
#define M1_PWM_UH_GPIO_Port GPIOA
#define M1_PWM_VH_Pin GPIO_PIN_9
#define M1_PWM_VH_GPIO_Port GPIOA
#define M1_PWM_WH_Pin GPIO_PIN_10
#define M1_PWM_WH_GPIO_Port GPIOA
#define TMS_Pin GPIO_PIN_13
#define TMS_GPIO_Port GPIOA
#define TCK_Pin GPIO_PIN_14
#define TCK_GPIO_Port GPIOA

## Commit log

2024-09-13 KiCad ini
    [Kers.kicad_pcb, Kers.kicad_sch]
2024-09-13 New KiCad
    [Kers.kicad_pcb, Kers.kicad_sch]
2024-09-13 Test circuit
    [Kers.kicad_sch]
2024-09-13 KiCad lib
    [000554_A_1-cell_stack_upper_print.stp, 000904_A_1-MAG_CON_5468.stp, 001797_A_1-TO247-4.stp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]
2024-09-20 STM32 init
    [000554_A_1-cell_stack_upper_print.stp, 000904_A_1-MAG_CON_5468.stp, 001797_A_1-TO247-4.stp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]
2024-10-13 Projectmanagement directory with kers schematic and time planing
2024-10-13 Mechanics cargo template from Andreas
    [Cargo_Bike_3D_Model.f3d]
2024-10-15 Added Bestellungen Mechanic
    [Bestellungen_Mechanik.xlsx]
2024-10-15 Updated Bestellungen_Mechanik
    [Bestellungen_Mechanik.xlsx]
2024-10-17 Remove pcb design files
    [Kers.kicad_pcb, Kers.kicad_sch]
2024-10-26 Electronics: White paper for bldc control
2024-10-26 Electronics: Update order list for 2 motors (front and back)
2024-10-26 Plot velocity per rpm from wheel diameter (front and back)
2024-10-29 Mechanics: Better legend for velocity/rpm plot
2024-11-01 Projectmanagement: Update Schematic with old motorcontroller + mcu
2024-11-02 Datenblätter Caps und MCU
2024-11-02 Software: Example motor workbench project for steval spin3201
2024-11-08 test board
2024-11-11 try to connect board
2024-11-16 Schaltplan erstellt
    nicht mal die Vorabversion
2024-11-17 Software: State diagram - enable exit of drive/brake state with throttle input (safety)
2024-11-18 Software: Replace throttle with switch in state diagram because more generic
2024-11-22 Update KERS-WD.pdf
    Wiring diagram completed
2024-12-01 Mechanics: Add second x-axis for electrical rotational speed
2024-12-01 Mechanics: Plot mech. and elec. speed for given velocity
2024-12-01 Software: Add schematic for steval spin mcu
2024-12-08 Motor profiling Windmeile - front
2025-01-09 Ele-Box CAD
    [EleBox_oben.stp, EleBox_unten.stp]
2025-03-02 Better plot for velocity over rpm
2025-03-02 Add battery to overview picture
2025-03-02 Last attempt to ramp up motor
2025-03-02 Ele-Box neu
    [EleBox_oben.stp, EleBox_unten.stp, Platinenadapter.stp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]

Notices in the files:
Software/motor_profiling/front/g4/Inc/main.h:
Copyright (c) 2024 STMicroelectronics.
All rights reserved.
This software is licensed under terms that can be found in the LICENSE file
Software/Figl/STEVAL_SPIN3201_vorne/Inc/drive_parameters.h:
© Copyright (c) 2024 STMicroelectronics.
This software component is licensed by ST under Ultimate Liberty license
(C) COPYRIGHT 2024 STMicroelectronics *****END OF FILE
